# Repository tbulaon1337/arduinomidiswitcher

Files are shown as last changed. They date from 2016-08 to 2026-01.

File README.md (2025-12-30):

Arduino Mega MIDI Loop Switcher (Open Source)

This project is an open-source Arduino Mega 2560–based MIDI loop switcher designed for guitar and bass rigs that need predictable, preset-driven control with optional stompbox-style flexibility.

It combines:

true-bypass relay switching,

per-preset MIDI control,

stompbox and preset modes,

MIDI clock sync via tap tempo,

and a hardware-first UI.

The design goal is simple:
nothing changes unless you press something.

This project is intentionally scoped for the Arduino Mega 2560 due to I/O count, memory headroom, and predictable timing.

Current Features
Core Switching

3–5 true-bypass relay loops (configurable in code)

Relay control via ULN2803A

Optional relay output for amp channel switching

MIDI

MIDI Program Change (PC)

MIDI Control Change (CC)

Per-preset MIDI channel assignment

MIDI clock sync OUT

Tap tempo generates MIDI clock

MIDI OUT only (no MIDI IN)

Presets & Banks

Preset-based architecture (relay states + MIDI data)

Unlimited banks (EEPROM-limited)

Each bank holds multiple presets

Preset changes occur only on footswitch press

Bank navigation does not trigger MIDI or relay changes

Stompbox Mode

Stompbox mode can be enabled per preset

Individual loops can be toggled on/off like traditional pedals

Preset defines:

which loops are active

whether the preset behaves as a “fixed scene” or a stompbox-style layout

No global mode switching required

User Interface

SSD1306 OLED display

Rotary encoder with push button

Dedicated navigation buttons

On-device menu system for:

preset editing

MIDI settings

stompbox configuration

expression calibration

Footswitching

Multiple footswitches for preset selection and loop control

Bank up / bank down switches

Debounced, state-safe logic

No background state mutation

Expression / Control

Expression pedal input (ADC)

Assignable CC output

Heel/toe calibration stored in config

Optional global default EXP CC

Bill of Materials (Core)

Controller & Logic

Arduino Mega 2560

ULN2803A Darlington array

Logic ICs as required (74HC series)

Display & UI

SSD1306 128×64 OLED (I2C)

Rotary encoder with push button

Tactile push buttons

Momentary footswitches (soft-touch)

Switching

Signal relays (e.g. Omron G6K-2 or equivalent)

Power

9V DC input

Buck converter (9V → 5V)

Power filtering:

220µF electrolytic capacitor

0.1µF ceramic decoupling capacitors

I/O

¼″ mono jacks (loops, amp switching)

MIDI OUT (5-pin DIN or TRS MIDI)

Expression pedal jack (TRS)

Indicators

LEDs + current-limiting resistors

Misc

Enclosure (Hammond / equivalent)

Stripboard or custom PCB

Wire, headers, standoffs, hardware

LEGACY CODE FOR OLD ARDUINO BASED MIDI SWITCHER WILL BE LABELED AS LEGACY.

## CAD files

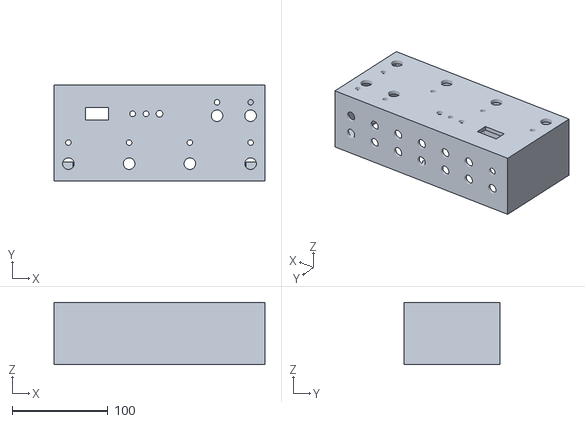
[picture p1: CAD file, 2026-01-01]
Looper Box 220mm 4 Footswitch/Looper Box 220mm 4 Footswitch.stl
220.0 x 100.0 x 65.0

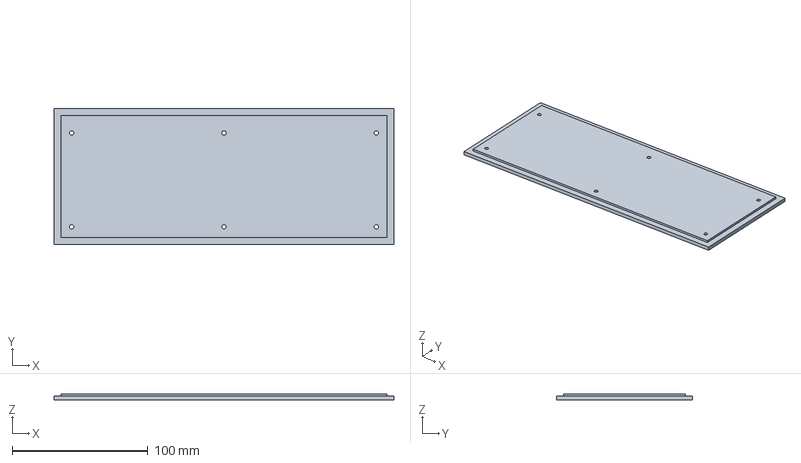
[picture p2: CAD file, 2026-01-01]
Looper Box 250mm/Looper Box 250mm Lid.3mf
250.0 x 100.0 x 4.70 mm

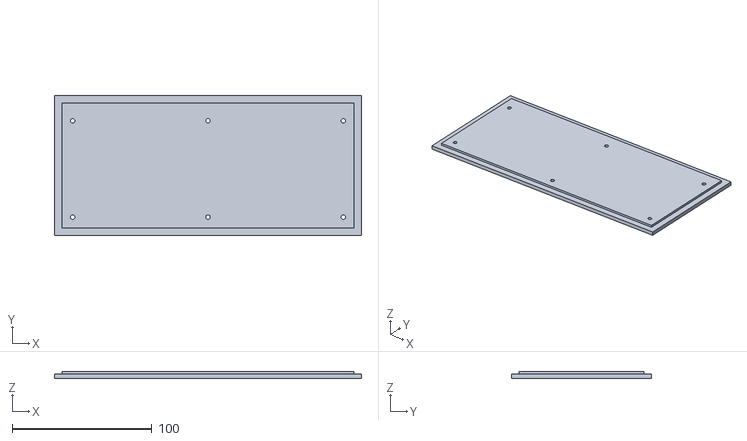
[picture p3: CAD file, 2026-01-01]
Looper Box 220mm 4 Footswitch/Looper Box 220mm 4 Footswitch Lid.stl
220.0 x 100.0 x 4.70

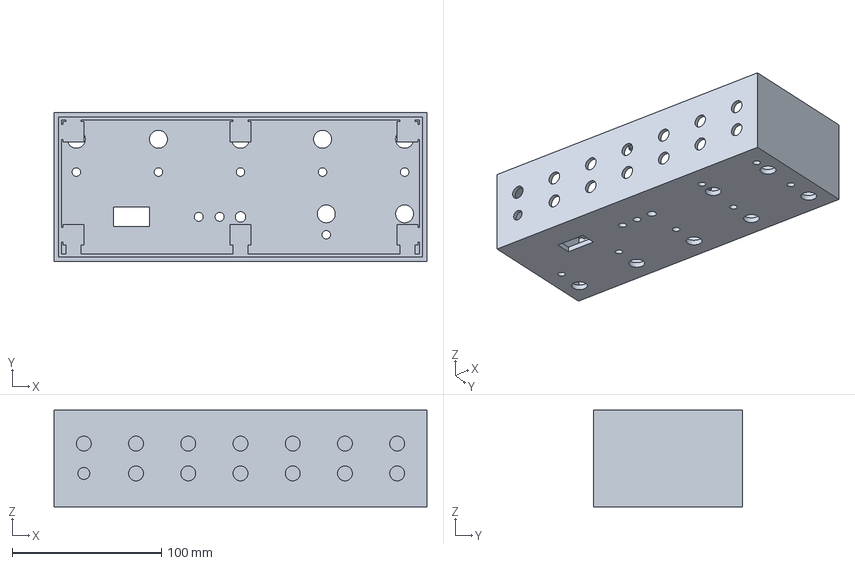
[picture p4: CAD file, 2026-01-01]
Looper Box 250mm/Looper Box 250mm.3mf
250.0 x 100.0 x 65.0 mm

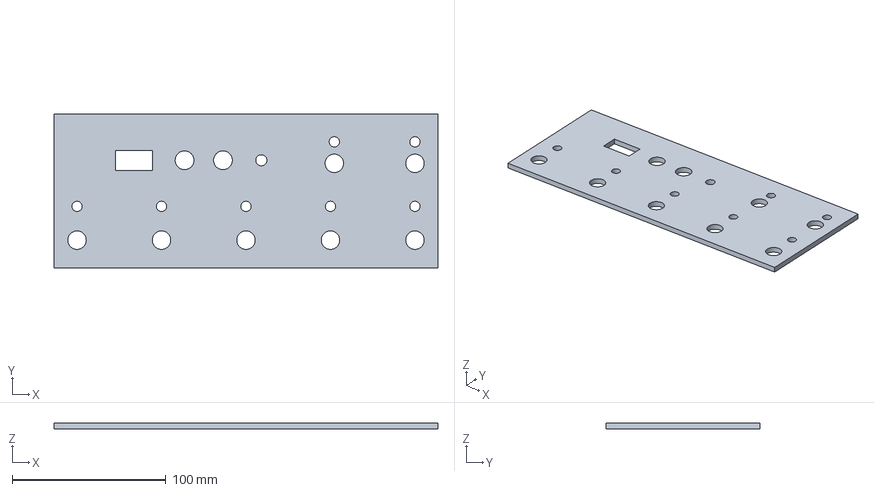
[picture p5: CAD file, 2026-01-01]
Looper Box 250mm/Test top plate.3mf
250.0 x 100.0 x 4.00 mm

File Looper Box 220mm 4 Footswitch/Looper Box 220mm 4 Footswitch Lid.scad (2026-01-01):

// Matching LID for 220 x 100 x 65 enclosure (body: WALL=3, TOP_WALL=4, LIP_H=2, LIP_W=2)
// - Flat plate with centering tongue against inner lip
// - M3 clearance holes + counterbores aligned to blended boss blocks
// - Body's rear bosses are at by2 = D - WALL - 15 (moved forward) — mirrored here

// ---------- must match BODY ----------
W = 220;
D = 100;
WALL = 3;
LIP_H = 2;
LIP_W = 2;
$fn = 80;

// ---------- lid parameters ----------
LID_T    = 3.0;    // lid thickness
TONGUE_H = 1.7;    // slightly less than lip (easy fit)
CL       = 0.30;   // clearance around tongue

// ---------- screw holes (M3 through, heads recessed) ----------
M3_CLR_D = 3.2;    // through-hole in lid
CB_D     = 6.5;    // counterbore diameter
CB_T     = 1.8;    // counterbore depth

// ---------- derived (match body cavity & boss XY) ----------
innerW = W - 2*WALL;
innerD = D - 2*WALL;

// Boss coordinates (MUST match body)
// bx1=WALL+10; bx2=W-WALL-10; bxm=W/2;
// by1=WALL+10; by2=D-WALL-15;   // note: -15 per your latest body
bx1 = WALL + 10;
bx2 = W - WALL - 10;
bxm = W/2;
by1 = WALL + 10;
by2 = D - WALL - 15;

boss_xy = [
  [bx1,by1],[bx2,by1],   // front corners
  [bx1,by2],[bx2,by2],   // rear corners (moved forward)
  [bxm,by1],[bxm,by2]    // front & rear mid
];

// ---------- model ----------
module lid_plate(){
  difference(){
    // Plate + centering tongue
    union(){
      // main plate
      cube([W, D, LID_T]);

      // centering tongue (fits inside, clears lip by CL)
      translate([WALL + LIP_W + CL, WALL + LIP_W + CL, LID_T])
        cube([ innerW - 2*LIP_W - 2*CL,
               innerD - 2*LIP_W - 2*CL,
               TONGUE_H ]);
    }

    // through-holes + counterbores at boss centers
    for (p = boss_xy){
      // through (M3 clearance)
      translate([p[0], p[1], -0.1])
        cylinder(h = LID_T + TONGUE_H + 1.0, d = M3_CLR_D);

      // counterbore from outside face (bottom of lid)
      translate([p[0], p[1], 0])
        cylinder(h = CB_T, d = CB_D);
    }
  }
}

// render lid
lid_plate();

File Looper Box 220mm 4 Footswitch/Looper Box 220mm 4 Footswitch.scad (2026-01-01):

// Enclosure BODY — 220 x 100 x 65, 3 mm walls, thicker top (4 mm), open bottom
// Top: 4 front FS (Ø12) with 4 LEDs aligned (6.7 mm), 2 back FS (Tap + Aux)
//       Tap LED above Tap FS, Aux LED above Aux FS
// Rear (two even rows, NO USB):
//   Top (7): DC(Ø8), MIDI TRS 6.35, IN, OUT, SEND1, SEND2, SEND3
//   Bot (7): SEND4, RETURN1, RETURN2, RETURN3, RETURN4, TRS SEND/RETURN 5, EXPRESSION TRS
// Notes: straight rows; bottom-edge chamfers to reduce PLA warping; blended bosses (no pilot/nubs)

// ---------- size ----------
W=220; D=100; H=65; WALL=3;
TOP_WALL=4;
$fn=80;

// ---------- hole sizes ----------
D_FOOT = 12.0;   // footswitches
D_LED  = 5.7;    // 3 mm LED bezel panel hole (bezel OD)
D_JACK = 10.0;   // 6.35 mm Lumberg compact (mono/TRS)
DC_D   = 8.0;    // DC barrel jack

// ---------- top layout ----------
FS_FRONT_Y=18;
FS_BACK_Y =68;

// Front footswitches (4 evenly spaced)
front_margin = 15;
front_span   = W - 2*front_margin;
function fxf(i) = front_margin + front_span*(i/3);  // i=0..3
fs_front_x = [ for (i=[0:3]) fxf(i) ];

// Back footswitches: Tap aligned with front FS #4 (rightmost), Aux offset from Tap
aux_right_offset = 35;
fs_back_x_tap = fs_front_x[3];
right_limit   = W - front_margin;
desired_right = fs_back_x_tap + aux_right_offset;
desired_left  = fs_back_x_tap - aux_right_offset;
fs_back_x_aux = (desired_right <= right_limit) ? desired_right : max(front_margin, desired_left);

// LEDs aligned with front FS (nudged up for more room above switches)
LED_Y_ROW = 40;  // was 36
led_xy = [ for (xv = fs_front_x) [xv, LED_Y_ROW] ];

// Tap & Aux LEDs above the back FS
TAP_LED_X = fs_back_x_tap;
AUX_LED_X = fs_back_x_aux;
TAP_LED_Y = FS_BACK_Y + 14;  // raised a touch
AUX_LED_Y = FS_BACK_Y + 14;

// Controls
OLED_W=24; OLED_H=13; OLED_X=45; OLED_Y=70;
ENC_X=110; ENC_Y=70; ENC_D=7;
BTN1_X=96; BTN2_X=82; BTN_Y=70; BTN_D=6;

// ---------- rear layout (TWO even rows, 7 + 7) ----------
REAR_Z_TOP = H/2 + 10;
REAR_Z_BOT = H/2 - 10;

// Keep more side clearance; also ensure clearance from rear-wall bosses
rear_margin = 20;                 // was 18 (gives extra room vs side bosses)
rear_span   = W - 2*rear_margin;

function rxt(i) = rear_margin + rear_span*(i/6);  // 7 columns -> i=0..6
function rxb(i) = rear_margin + rear_span*(i/6);  // 7 columns -> i=0..6

// TOP row order: DC, MIDI, IN, OUT, S1, S2, S3
rear_top = [
  [rxt(0), REAR_Z_TOP, DC_D  ],
  [rxt(1), REAR_Z_TOP, D_JACK],
  [rxt(2), REAR_Z_TOP, D_JACK],
  [rxt(3), REAR_Z_TOP, D_JACK],
  [rxt(4), REAR_Z_TOP, D_JACK],
  [rxt(5), REAR_Z_TOP, D_JACK],
  [rxt(6), REAR_Z_TOP, D_JACK]
];

// BOTTOM row order: S4, R1, R2, R3, R4, TRS S/R 5, EXP TRS
rear_bot = [
  [rxb(0), REAR_Z_BOT, D_JACK],
  [rxb(1), REAR_Z_BOT, D_JACK],
  [rxb(2), REAR_Z_BOT, D_JACK],
  [rxb(3), REAR_Z_BOT, D_JACK],
  [rxb(4), REAR_Z_BOT, D_JACK],
  [rxb(5), REAR_Z_BOT, D_JACK],
  [rxb(6), REAR_Z_BOT, D_JACK]
];

// ---------- lip / bosses ----------
LIP_H=2.0; LIP_W=2.0;
BOSS_H=10.0;
innerW=W-2*WALL; innerD=D-2*WALL;

// Boss anchor positions (blended blocks)
// Pull the rear bosses 5 mm farther from the back wall for jack/nut clearance
bx1=WALL+10; bx2=W-WALL-10; bxm=W/2;
by1=WALL+10; 
by2=D-WALL-15;   // was D-WALL-10 -> more clearance to rear jacks
boss_xy=[[bx1,by1],[bx2,by1],[bx1,by2],[bx2,by2],[bxm,by1],[bxm,by2]];

// ---------- modules ----------
module solid_with_lip(){
  // outer minus interior cavity (leaves TOP_WALL thickness)
  difference(){
    cube([W,D,H]);
    translate([WALL,WALL,0]) cube([innerW,innerD,H-TOP_WALL]);
  }
  // inner lip ring
  translate([WALL,WALL,WALL])
    difference(){
      cube([innerW,innerD,LIP_H]);
      translate([LIP_W,LIP_W,-0.05])
        cube([innerW-2*LIP_W, innerD-2*LIP_W, LIP_H+0.1]);
    }
}

module all_cutters(){
  // TOP: front FS
  for(xv=fs_front_x)
    translate([xv,FS_FRONT_Y,H-TOP_WALL]) cylinder(h=TOP_WALL+1,d=D_FOOT);

  // TOP: back FS (Tap + Aux)
  translate([fs_back_x_tap,FS_BACK_Y,H-TOP_WALL]) cylinder(h=TOP_WALL+1,d=D_FOOT);
  translate([fs_back_x_aux,FS_BACK_Y,H-TOP_WALL]) cylinder(h=TOP_WALL+1,d=D_FOOT);

  // TOP: 4 LEDs aligned with front FS (nudged up)
  for(p=led_xy)
    translate([p[0],p[1],H-TOP_WALL]) cylinder(h=TOP_WALL+1,d=D_LED);

  // TOP: Tap & Aux LEDs above their switches
  translate([TAP_LED_X,TAP_LED_Y,H-TOP_WALL]) cylinder(h=TOP_WALL+1,d=D_LED);
  translate([AUX_LED_X,AUX_LED_Y,H-TOP_WALL]) cylinder(h=TOP_WALL+1,d=D_LED);

  // TOP: OLED + controls
  translate([OLED_X-OLED_W/2,OLED_Y-OLED_H/2,H-TOP_WALL]) cube([OLED_W,OLED_H,TOP_WALL+1]);
  translate([ENC_X,ENC_Y,H-TOP_WALL]) cylinder(h=TOP_WALL+1,d=ENC_D);
  translate([BTN1_X,BTN_Y,H-TOP_WALL]) cylinder(h=TOP_WALL+1,d=BTN_D);
  translate([BTN2_X,BTN_Y,H-TOP_WALL]) cylinder(h=TOP_WALL+1,d=BTN_D);

  // REAR: two rows (short bores through rear wall)
  for(r=rear_top) translate([r[0], D+5, r[1]]) rotate([90,0,0]) cylinder(h=WALL+6, d=r[2]);
  for(r=rear_bot) translate([r[0], D+5, r[1]]) rotate([90,0,0]) cylinder(h=WALL+6, d=r[2]);
}

// Blended boss (rectangular block tied into wall) — NO pilot holes (flat tops)
module wall_boss(xc, yc){
  boss_size = 14;                   // footprint width (square)
  boss_h    = LIP_H + BOSS_H;
  translate([xc - boss_size/2, yc - boss_size/2, WALL])
    cube([boss_size, boss_size, boss_h]);
}

// Ribs (beefier)
RIB_W=10;
module rib_front(xc,yc){ translate([xc-RIB_W/2, WALL, WALL]) cube([RIB_W, yc-WALL+7, LIP_H+BOSS_H]); }
module rib_back (xc,yc){ translate([xc-RIB_W/2, yc-7, WALL]) cube([RIB_W, D-WALL-(yc-7), LIP_H+BOSS_H]); }
module rib_left (xc,yc){ translate([WALL, yc-RIB_W/2, WALL]) cube([xc-WALL+7, RIB_W, LIP_H+BOSS_H]); }
module rib_right(xc,yc){ translate([xc-7, yc-RIB_W/2, WALL]) cube([W-WALL-(xc-7), RIB_W, LIP_H+BOSS_H]); }

// Bottom-edge chamfers (2 mm 45°)
CHAMFER=2;
module subtract_bottom_chamfers(){
  module edge_wedge_x(y0){
    translate([0,y0,0]) rotate([0,90,0])
      linear_extrude(height=W) polygon(points=[[0,0],[CHAMFER,0],[0,CHAMFER]]);
  }
  module edge_wedge_y(x0){
    translate([x0,0,0]) rotate([-90,0,0])
      linear_extrude(height=D) polygon(points=[[0,0],[CHAMFER,0],[0,CHAMFER]]);
  }
  edge_wedge_x(0);
  edge_wedge_x(D-CHAMFER);
  edge_wedge_y(0);
  edge_wedge_y(W-CHAMFER);
}

// ---------- CSG ----------
difference(){
  solid_with_lip();
  all_cutters();
  subtract_bottom_chamfers();
}

// ---------- bosses & ribs ----------
for(p=boss_xy) wall_boss(p[0],p[1]);
for(p=boss_xy){
  xc=p[0]; yc=p[1];
  if(yc==by1) rib_front(xc,yc);
  if(yc==by2) rib_back (xc,yc);
  if(xc==bx1) rib_left (xc,yc);
  if(xc==bx2) rib_right(xc,yc);
}

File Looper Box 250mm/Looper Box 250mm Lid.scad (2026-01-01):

// Matching LID for 250 x 100 x 65 enclosure
// Body refs: WALL=3, TOP_WALL=4 (not used here), LIP_H=2, LIP_W=2
// Bosses: bx1=WALL+10, bx2=W-WALL-10, bxm=W/2; by1=WALL+10, by2=D-WALL-15

// ---------- must match BODY ----------
W = 250;
D = 100;
WALL = 3;
LIP_H = 2;
LIP_W = 2;
$fn = 80;

// ---------- lid parameters ----------
LID_T     = 3.0;   // plate thickness
TONGUE_H  = 1.7;   // a bit under lip height for easy fit
CL        = 0.30;  // clearance around tongue vs inner lip/cavity

// ---------- screw holes (M3) ----------
M3_CLR_D  = 3.2;   // through-hole
CB_D      = 6.5;   // counterbore diameter
CB_T      = 1.8;   // counterbore depth

// ---------- derived from body ----------
innerW = W - 2*WALL;
innerD = D - 2*WALL;

// Boss coordinates (MUST match body)
bx1 = WALL + 10;
bx2 = W - WALL - 10;
bxm = W/2;

by1 = WALL + 10;
by2 = D - WALL - 15;   // rear bosses moved forward in body

boss_xy = [
  [bx1,by1],[bx2,by1],   // front corners
  [bx1,by2],[bx2,by2],   // rear corners
  [bxm,by1],[bxm,by2]    // mid front & mid rear
];

// ---------- model ----------
module lid_plate(){
  difference(){
    // plate + centering tongue
    union(){
      // main plate (z: 0..LID_T)
      cube([W, D, LID_T]);

      // centering tongue (fits inside body against inner lip)
      translate([WALL + LIP_W + CL, WALL + LIP_W + CL, LID_T])
        cube([
          innerW - 2*LIP_W - 2*CL,
          innerD - 2*LIP_W - 2*CL,
          TONGUE_H
        ]);
    }

    // through-holes + counterbores at boss centers
    for (p = boss_xy){
      // M3 clearance through
      translate([p[0], p[1], -0.1])
        cylinder(h = LID_T + TONGUE_H + 1.0, d = M3_CLR_D);

      // counterbore from the outside face (bottom of the lid)
      translate([p[0], p[1], 0])
        cylinder(h = CB_T, d = CB_D);
    }
  }
}

// render lid
lid_plate();

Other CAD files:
Looper Box 250mm/Looper Box 250mm.scad
Looper Box 250mm/Looper Box 250mm Lid.stl
Looper Box 250mm/Looper Box 250mm.stl
Looper Box 250mm/Test top plate.scad
Looper Box 250mm/Test top plate.stl

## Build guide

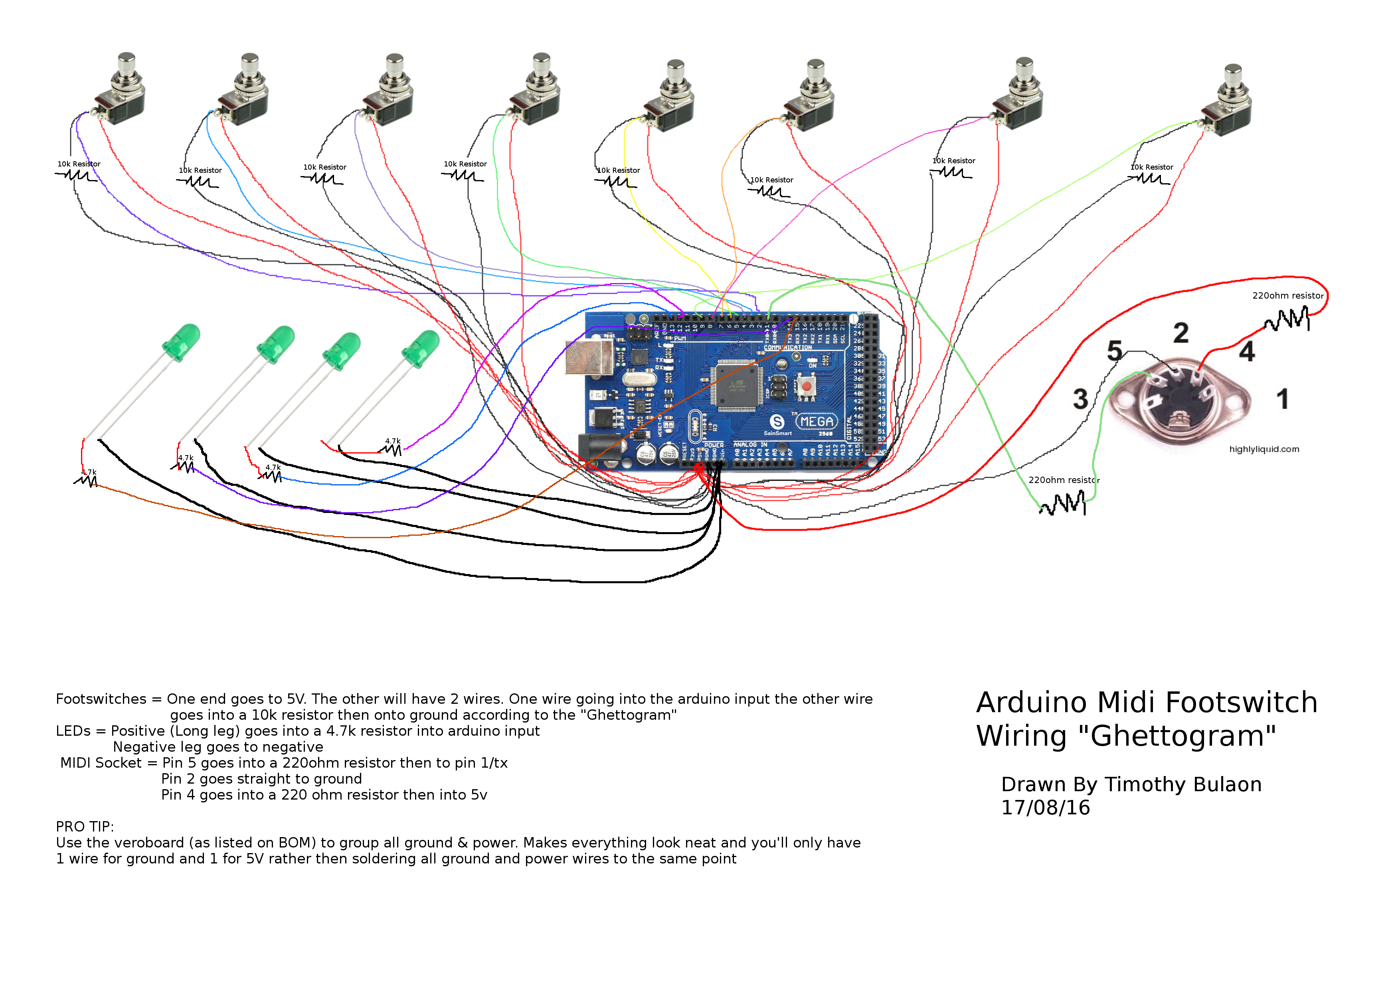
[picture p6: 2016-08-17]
Wiring Diagramv2.png

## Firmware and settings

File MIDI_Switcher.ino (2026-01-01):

// ===================== MIDI_Switcher.ino =====================
#include <Arduino.h>
#include <Wire.h>

#include "config.h"
#include "config_store.h"
#include "display.h"
#include "encoder.h"
#include "menu.h"
#include "midi.h"
#include "presets.h"
#include "relay_logic.h"
#include "taptempo.h"
#include "leds.h"


// ====== Global state (define once here; declared extern in headers) ======
bool        isStompboxMode      = false;   // runtime mode
int         currentBank          = 0;       // 0..NUM_BANKS-1
int         selectedSlot         = 0;       // 0..PRESETS_PER_BANK-1

bool        loopStates[NUM_RELAYS] = { false, false, false, false, false };
bool        relay5_isAmpSwitch     = false; // set by preset.relay5Mode
Preset      activePreset;
bool        haveActivePreset = false;

// Global config (persisted via config_store.*)
int         altBank            = 0;         // kept for menu compatibility
bool        startupIsStomp     = false;     // persisted startup mode
int         startupBank        = 0;         // persisted startup bank
uint16_t    defaultBPM         = 120;       // optional default BPM

// MIDI globals
byte        midiChannel        = 1;         // 1..16
bool        midiClockEnabled   = false;     // on/off
uint16_t    currentBPM         = 120;       // live BPM for clock/tap

// Menu state lives here (referenced by menu.cpp)
MenuState   menuState          = MENU_NONE;

// ============================== Expression pedal ==============================
// Per-preset EXP settings live inside activePreset (loaded on recall / save)
// EXP sends CC only when activePreset.expEnable == 1

// Calibration / runtime state (you can later persist calibration if you want)
static uint16_t expMinRaw   = 0;
static uint16_t expMaxRaw   = 1023;

static uint16_t expSmoothed = 0;
static byte     expLastCC   = 255;   // 255 = "unset"
static uint32_t expLastSend = 0;     // ms throttle

static inline void setupExpression() {
  pinMode(EXP_PEDAL_PIN, INPUT);
  expSmoothed = analogRead(EXP_PEDAL_PIN);
  expLastCC   = 255;
  expLastSend = 0;
}

static inline void pollExpression() {
  // Need a valid active preset first
  if (!haveActivePreset) return;

  // Only send if this preset enables EXP
  if (activePreset.expEnable == 0) return;

  // CC number (safe fallback)
  byte ccNum = activePreset.expCC;
  if (ccNum > 127) ccNum = 11;
  if (ccNum == 0)  ccNum = 11; // optional: treat 0 as "unset"

  // Read raw (0..1023)
  uint16_t raw = analogRead(EXP_PEDAL_PIN);

  // Smooth: expSmoothed = 0.75*old + 0.25*new
  expSmoothed = (expSmoothed * 3 + raw) >> 2;

  // Clamp to calibration window
  uint16_t lo = (expMinRaw < expMaxRaw) ? expMinRaw : expMaxRaw;
  uint16_t hi = (expMinRaw < expMaxRaw) ? expMaxRaw : expMinRaw;
  uint16_t clamped = expSmoothed;
  if (clamped < lo) clamped = lo;
  if (clamped > hi) clamped = hi;

  // Map to 0..127
  uint16_t span = (hi > lo) ? (hi - lo) : 1;
  uint16_t pos  = (uint32_t)(clamped - lo) * 127UL / span;
  byte ccVal    = (byte)pos;

  // Optional invert (per preset)
  if (activePreset.expInvert) ccVal = 127 - ccVal;

  // Send only when changed, throttle a little
  uint32_t now = millis();
  if (ccVal != expLastCC && (now - expLastSend) > 8) {
    sendCC(ccNum, ccVal);
    expLastCC   = ccVal;
    expLastSend = now;
  }
}


// ============================== Forward decls ==============================
void setupDisplay();
void drawMainUI();      // display.cpp
void drawMenuUI();      // menu.cpp

void setupRelays();     // relay_logic.cpp
void updateRelays();

void setupMIDI();       // midi.cpp
void updateMidiClock();

void setupEncoder();    // encoder.cpp
void checkEncoder();

void setupInputs();     // menu.cpp (FS1..FS5, TAP_TEMPO_PIN, MODE_BTN_PIN)
void pollInputs();      // includes FS1+FS2 / FS4+FS5 bank combos
void checkMenuButtons(); // BTN_BACK/BTN_SAVE

void loadGlobalConfig();  // config_store.cpp
void saveGlobalConfig();

// ============================== SETUP ==============================
void setup() {
  // Serial.begin(115200);  // (optional for debugging)
  Wire.begin();

  setupDisplay();
  setupRelays();
  setupMIDI();

  //Set up LEDS
  setupLeds();
  refreshLeds();

  // Load persisted configuration (startup mode/bank, MIDI, altBank, etc.)
  loadGlobalConfig();

  // Apply startup choices to runtime
  isStompboxMode = startupIsStomp;
  refreshLeds();
  // DEBUG: force stompbox mode on boot
  //isStompboxMode = true;
  //refreshLeds();
  currentBank    = constrain(startupBank, 0, NUM_BANKS - 1);
  selectedSlot   = constrain(selectedSlot, 0, PRESETS_PER_BANK - 1);

  // Controls
  setupInputs();      // 5 FS + TAP + MODE (no panel bank buttons)
  setupEncoder();     // rotary + push
  setupExpression();  // expression pedal analog in

  // Optionally boot directly into the current preset’s sound
 if (!isStompboxMode) {
  Preset p = loadPreset(currentBank, selectedSlot);
  activePreset = p;
  haveActivePreset = true;
  applyPresetToHardware(p);
}

  drawMainUI();
}

// =============================== LOOP ==============================
void loop() {
  // Inputs
  pollInputs();         // FS1..FS5, Tap, Mode (+ FS combos for bank up/down)
  checkEncoder();       // menu navigation
  checkMenuButtons();   // Back/Save

  // Continuous controls
  pollExpression();     // reads EXP_PEDAL_PIN and sends CC

  // Time-based systems
  updateMidiClock();    // 24 PPQN, gated by midiClockEnabled
  
  //Set up tap tempo LED
  tickLeds();

  // UI
  if (menuState == MENU_NONE) {
    drawMainUI();
  } else {
    drawMenuUI();
  }
}

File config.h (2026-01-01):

#pragma once
#include <Arduino.h>
#include <EEPROM.h>
#include <Wire.h>
#include <Adafruit_GFX.h>
#include <Adafruit_SSD1306.h>
#include <MIDI.h>

// ================= Project sizes =================
#define NUM_RELAYS        5
#define PRESETS_PER_BANK  5
#define NUM_BANKS         35
#define BYTES_PER_PRESET  11   // UPDATED: now 11 bytes per preset (Mega EEPROM is fine)

// Name Saves
#define PRESET_NAME_LEN 12     // 12 chars max (OLED-friendly)

// ================= OLED =================
#define SCREEN_WIDTH   128
#define SCREEN_HEIGHT  64
#define OLED_ADDR      0x3C

// ================= Pin map =================

// ---------- Relays ----------
#define RELAY_PINS        {22, 23, 24, 25, 26}

// ---------- Footswitches ----------
#define FOOTSWITCH_PINS   {30, 31, 32, 33, 34}

// ---------- Rotary encoder ----------
#define ENCODER_CLK       A0
#define ENCODER_DT        A1
#define ENCODER_SW        A2

// ---------- Panel tactiles ----------
#define BTN_BACK          37
#define BTN_SAVE          38

// ---------- Dedicated switches ----------
#define TAP_TEMPO_PIN     35
#define MODE_BTN_PIN      36

// ---------- Loop/Preset LEDs ----------
#define LOOP_LED_PINS     {41, 42, 43, 44, 45}

// ---------- Status LEDs ----------
#define TAP_LED_PIN       46
#define MODE_LED_PIN      47

// ---------- Expression pedal ----------
#define EXP_PEDAL_PIN     A5

// ================= Timing constants =================
#define DEBOUNCE_MS       35
#define COMBO_LATCH_MS    150

// ================= Preset structure =================
// EXACTLY 11 bytes now
struct Preset {
  uint8_t loopBits;     // bit0..4 = loops 1..5
  uint8_t relay5Mode;   // 0 = loop, 1 = amp channel
  uint8_t midiPC;       // 0–127
  uint8_t midiCC;       // 0–127
  uint8_t ccValue;      // 0–127

  // --- NEW: per-preset expression settings ---
  uint8_t expEnable;    // 0/1
  uint8_t expCC;        // 0–127 (default suggestion: 11)
  uint8_t expInvert;    // 0/1

  // spare
  uint8_t rsv1;
  uint8_t rsv2;
  uint8_t rsv3;
};

static_assert(sizeof(Preset) == BYTES_PER_PRESET, "Preset must be 11 bytes");

// ================= Global state (defined in MIDI_Switcher.ino) =================
extern bool        loopStates[NUM_RELAYS];
extern bool        relay5_isAmpSwitch;

extern bool        isStompboxMode;
extern int         currentBank;
extern int         selectedSlot;

extern int         altBank;
extern bool        startupIsStomp;
extern int         startupBank;
extern uint16_t    defaultBPM;

extern byte        midiChannel;
extern bool        midiClockEnabled;
extern uint16_t    currentBPM;

// ---- NEW: active preset snapshot (for stomp overlay + expression logic) ----
extern Preset      activePreset;
extern bool        haveActivePreset;

// ================= Menu / UI =================
enum MenuState { MENU_NONE, MENU_MAIN };
extern MenuState menuState;

// ================= Module interfaces =================

// Display
void setupDisplay();
void drawMainUI();
void drawMenuUI();
void displayShowMessage(const char* msg, uint16_t ms);
void displayShowRecall(int bank, int slot);

// Inputs
void setupInputs();
void pollInputs();
void checkMenuButtons();

// Encoder
void setupEncoder();
void checkEncoder();

// Relays
void setupRelays();
void setLoop(int loopNum, bool state);
void toggleLoop(int loopNum);
byte encodeLoopStates(bool loops[NUM_RELAYS]);
void decodeLoopStates(byte encoded, bool loops[NUM_RELAYS]);

// Presets
int  getPresetIndex(int bank, int slot);
int  getPresetAddress(int bank, int slot);
void savePreset(int bank, int slot, const Preset &p);
Preset loadPreset(int bank, int slot);
void applyPresetToHardware(const Preset &p);

// MIDI
void setupMIDI();
void sendPC(byte pc);
void sendCC(byte cc, byte value);
void midiClockStart();
void midiClockStop();
void updateMidiClock();

// Tap tempo
void checkTapTempo();
void taptempoTap();

// Config store
void saveGlobalConfig();
void loadGlobalConfig();

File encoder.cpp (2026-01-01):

// ===================== encoder.cpp =====================
#include "config.h"
#include "menu.h"

static int lastClk = HIGH;
static uint32_t lastStepMs = 0;
static const uint16_t ENC_DEBOUNCE_MS = 2; // 1–3ms is usually sweet

void setupEncoder() {
  lastClk = digitalRead(ENCODER_CLK);
}

void checkEncoder() {
  const uint32_t now = millis();
  const int clk = digitalRead(ENCODER_CLK);

  // Count only on a clean falling edge of CLK
  if (lastClk == HIGH && clk == LOW) {
    // optional tiny debounce
    if (now - lastStepMs >= ENC_DEBOUNCE_MS) {
      lastStepMs = now;

      // Direction: read DT at the moment CLK falls
      bool dirCW = (digitalRead(ENCODER_DT) == HIGH);

      if (menuState != MENU_NONE) {
        menuOnEncoder(dirCW);
      } else if (digitalRead(ENCODER_SW) == HIGH && isStompboxMode) {
        // adjust BPM only when not in menu and not pressing encoder
        currentBPM += dirCW ? 1 : -1;
        if (currentBPM < 40) currentBPM = 40;
        if (currentBPM > 300) currentBPM = 300;
      }
    }
  }

  lastClk = clk;

  // Encoder push
  if (digitalRead(ENCODER_SW) == LOW) {
    delay(150); // debounce
    if (menuState == MENU_NONE) {
      menuState = MENU_MAIN;
      menuEnter();
    } else {
      menuOnSelect();
    }
  }
}

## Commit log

2016-08-17 Add files via upload
    Bill of materials for Arduino Midi Switcher
2016-08-17 Add files via upload
    Heres the wiring diagram for those who need a little clarification on how to hook everything up. The drawing is so rough that I've called it a "Ghettogram"
2016-08-17 Delete BOM.pdf
    Made a mistake. Whoops
2016-08-17 Add files via upload
    Heres the bill of materials.
2016-08-17 Add files via upload
    Wiring Diagram Version 2. First version had some very humorous errors.
2016-08-18 Add files via upload
    Updated code for us with RGB LED. This allows you to use 1 RGB LED that changes colors with bank changes rather then using 4 LEDs if you so wish.
2016-08-18 Rename Source-Files/MidiSwitchLED-delyk.ino to Source-Files/MidiSwitchRGBLED/MidiSwitchLED-delyk.ino
    Remember to download the MidiSwitchSettings.h. When you open this .ino in arduino IDE make sure you put the MidiSwitchSettings.h in the same folder that the IDE creates.
2016-08-18 Create 8 Button Switcher
2026-01-01 Create BOM
